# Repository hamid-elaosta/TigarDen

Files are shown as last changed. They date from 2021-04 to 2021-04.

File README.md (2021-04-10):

# TigarDen

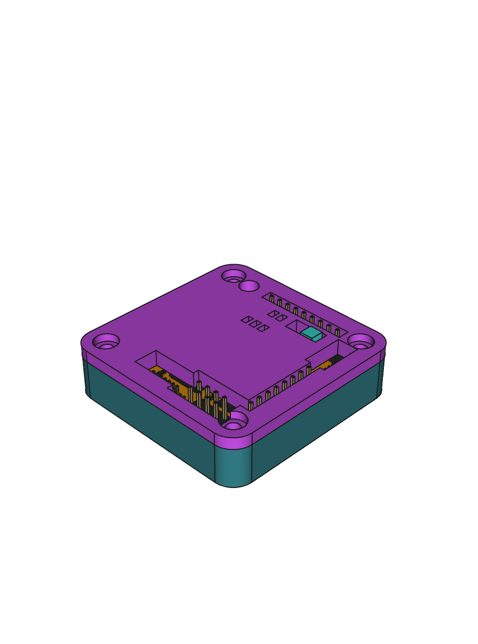
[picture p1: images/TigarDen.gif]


A 3D printable enclosure for the Tigard Open Source Hardware Hacking Tool from [Securing Hardware](https://securinghardware.com/)

# Enclosure

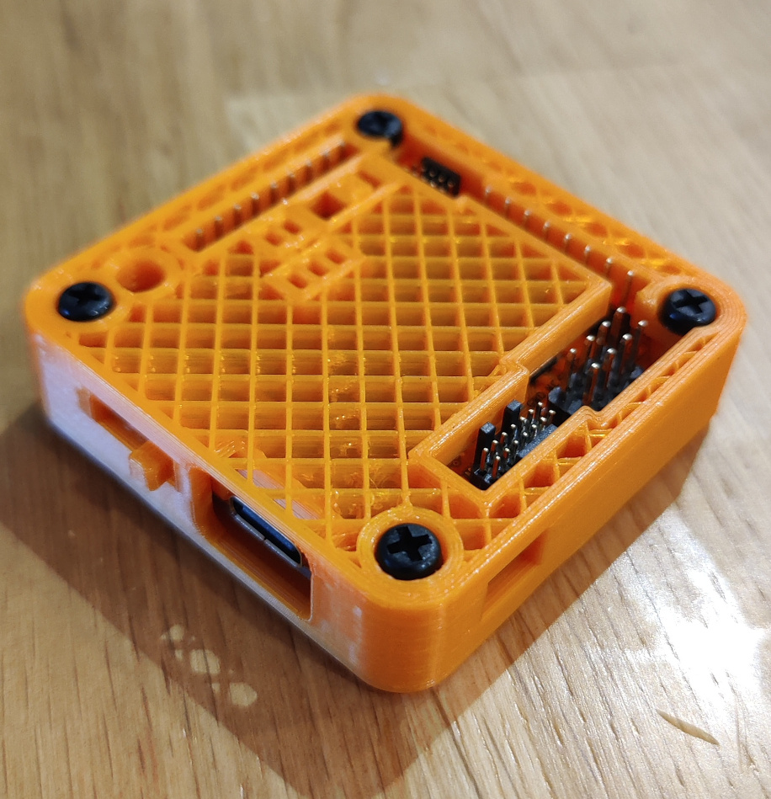
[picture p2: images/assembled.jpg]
 

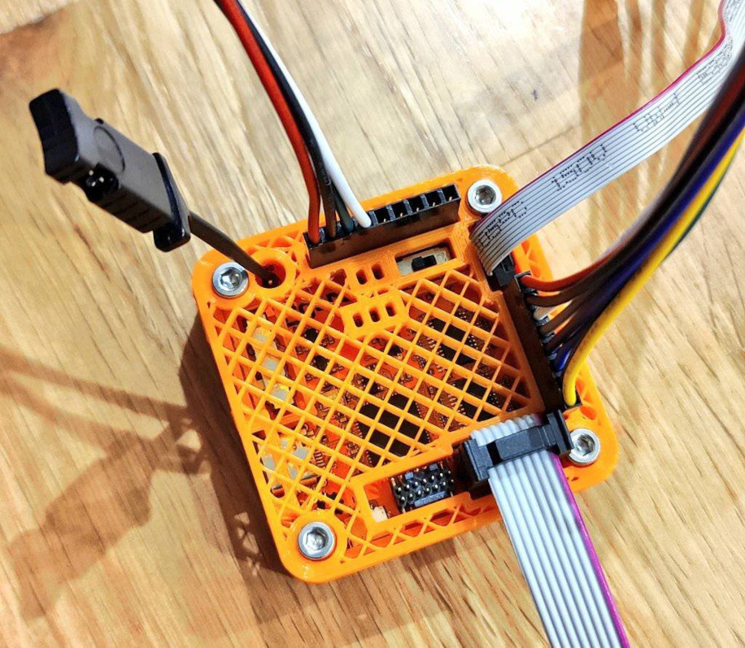
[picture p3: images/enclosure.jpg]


# Assembly Requirements

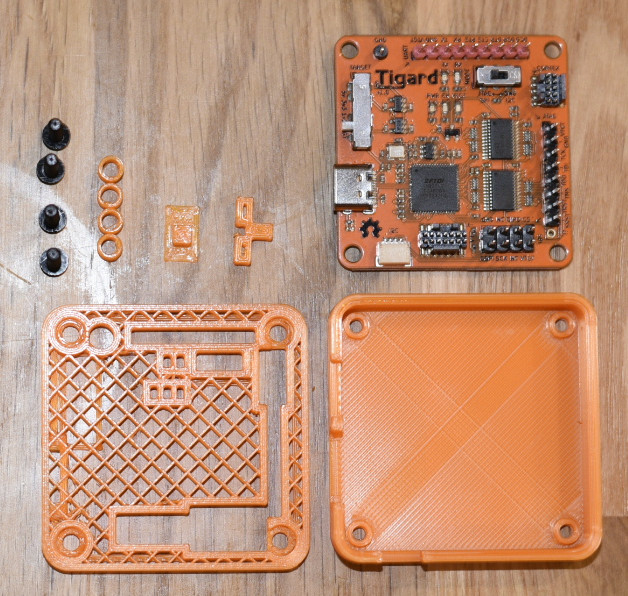
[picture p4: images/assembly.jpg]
 

* The enclosure comes in the following parts;
    * [top (STL)](Lid.stl)
    * [bottom (STL)](Base.stl)
    * [shim (STL)](Shim4mm.stl)
    * [voltage switch (STL)](VoltageSwitchNotched.stl)
    * [JTAG/SWD switch (STL)](JTAGSwitch.stl)

AND

* 4x M3x10; The base screw holes are sized for M3 tapping/self tapping (gently)
* 4x non-slip rubber feet for that extra flair (Optional)

OR
* 4x M3x14 Bolts
* 4x M3 Nyloc nuts as feet

# Printing

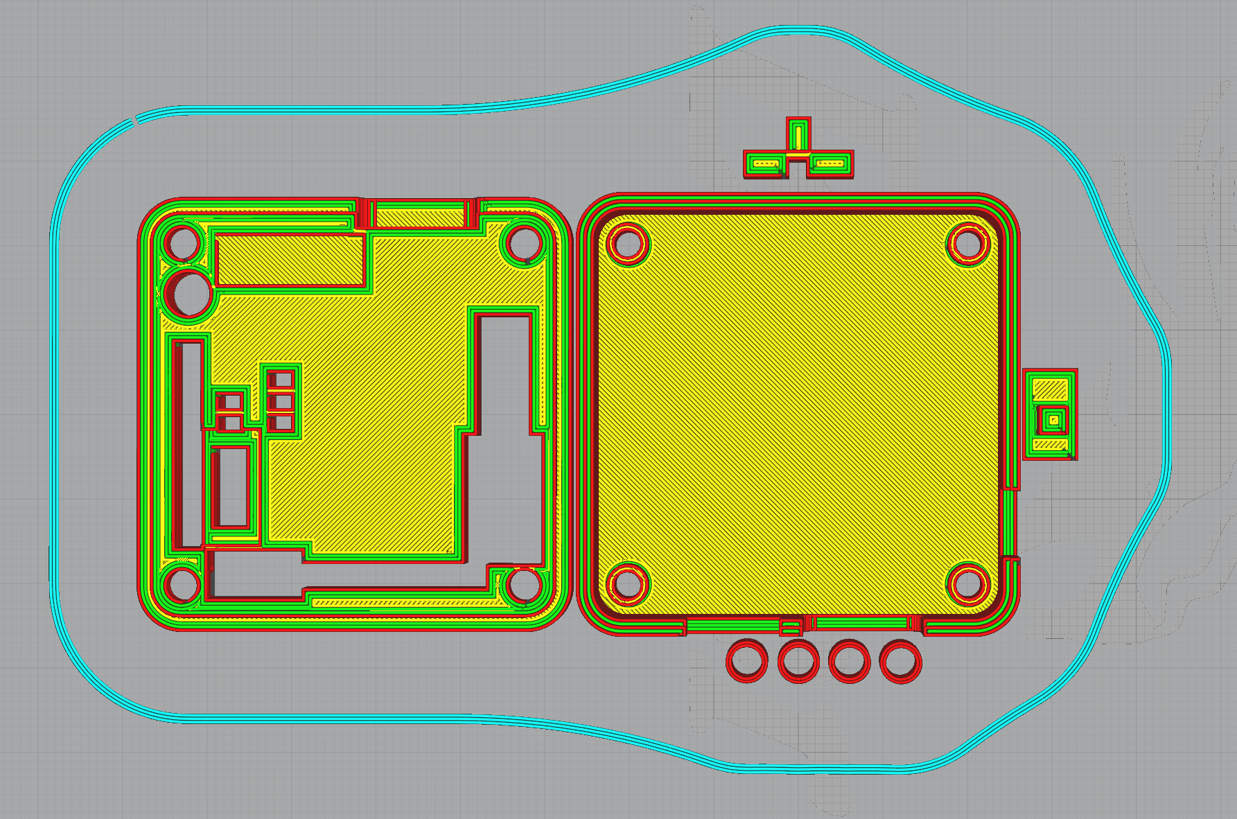
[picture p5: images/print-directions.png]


> Note: I don't recommend printing them all at once, you won't be able to select the top/bottomless grid for the lid this way anyway, this image is to indicate which way up to print. Voltage switch is printed notch-up.

For my print I sliced in Cura and printed at 0.2mm (Standard quality) (on an almost-stock Ender 3 V2), the tolerences in the design should be enough to allow for some variation in print quality.

Print the JTAG switch and base right-way-up, print the voltage switch (note it has a notch) and lid upside down; see below if you want to replicate the grid pattern.

> Note: The dimensions take into account the dimensions when printing without top and bottom layers for the lid, the lid may need adjustments if you choose to print with top and bottom layers on.

For the switches, I recommend printing multiples, spaced out on the print bed, this gives each layer time to cool before the next layer. I've found when printing tiny items like these, that the hotend will melt everything together if it stays over a small print too long, so i came up with this solution.

It means you have a few extras (if they print successfully) but a much higher chance of success in my experience.

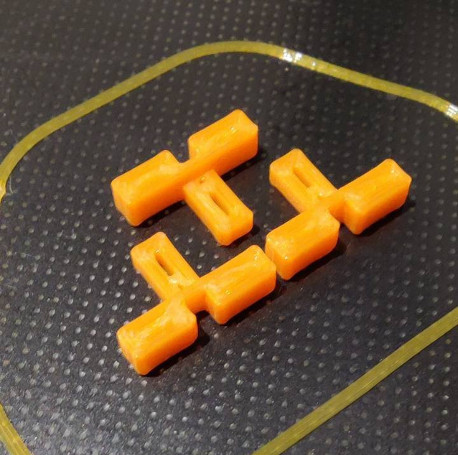
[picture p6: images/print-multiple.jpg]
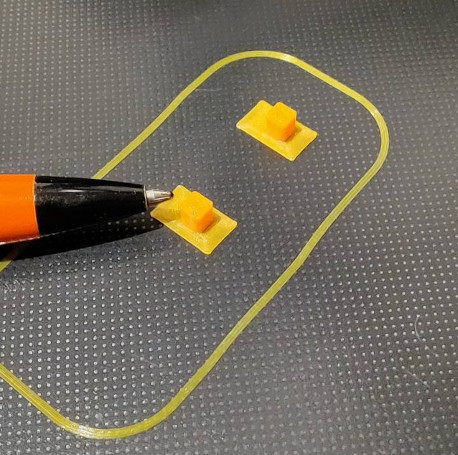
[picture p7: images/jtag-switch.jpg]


# Shims

The shims sit between the Tigard and the lid to hold it firmly in place so there is no play when connecting/disconnecting things to and from the board. The STL is exported at 4mm, these fit perfectly and the lid closes exactly with my print, but you may wish to export them again or modify the Z height in your slicer to adapt them.

# The Grid

If you wish to achieve the grid pattern shown in the photograph, disable top and bottom layers in your slicer, set infill type to "grid" and set your infill density according to the grid size you would like, the photo above is 25% infill.

# Modifying

The FreeCAD design file is [here](TigarDen.FCStd), modify to your hearts desire. I'm a FreeCAD/CAD beginner so I would appreciate any critique of the approach, raise a ticket or ping me on Twitter.

# Open Source Tools/Software

3D CAD model created with [FreeCAD 0.19 AppImage](https://freecadweb.org/) on [Manjaro Linux](https://manjaro.org/), images edited with [GIMP](https://www.gimp.org/), PNGs optimised with [pngcrush](https://pmt.sourceforge.io/pngcrush/), this document written in [VSCodium](https://vscodium.com/), prints sliced using [Ultimaker Cura](https://github.com/Ultimaker/Cura) and printed using [Marlin 2.0.x (3D Printer) Firmware](https://github.com/MarlinFirmware/Marlin).

# Links
* [Tigard Sources and Documentation](https://github.com/tigard-tools/tigard)
* [Tigard at Crowd Supply](https://www.crowdsupply.com/securinghw/tigard)

# License

Tigard is Copyright 2020 Franklin Harding CC BY-SA 4.0.

TigarDen © 2021 by Hamid Elaosta is licensed under CC BY-SA 4.0. To view a copy of this license, visit http://creativecommons.org/licenses/by-sa/4.0/

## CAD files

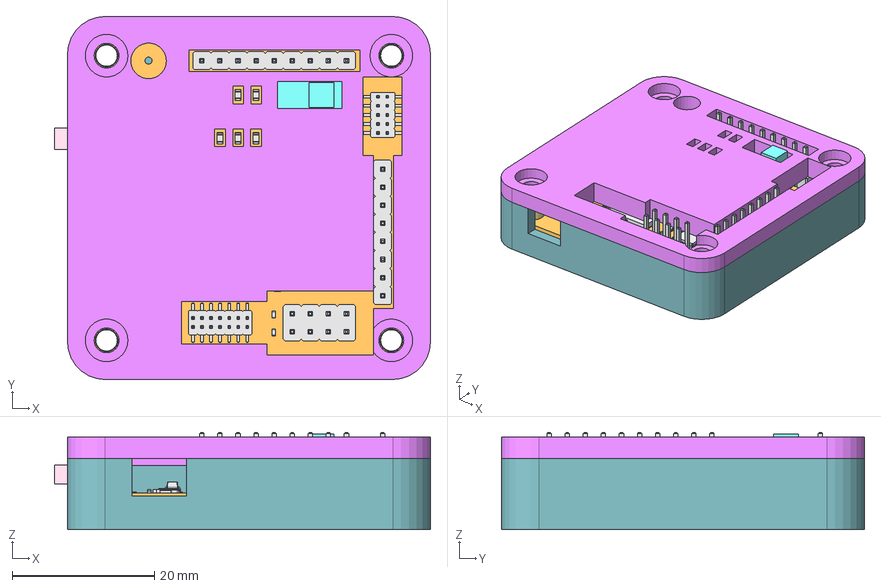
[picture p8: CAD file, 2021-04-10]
TigarDen.FCStd
52.8 x 51.0 x 13.6 mm
Pcb_1420
J6_PinHeader_2x07_P127mm_Vertical_SMD_5EEC7791
J1_Fusion_5EEC9037[2]
J2_PinHeader_1x08_P254mm_Vertical_5F30E631
U6_TSSOP_24_44x78mm_P065mm_5EEC89EE x 2
SW2_CuK_JS202011CQN_DPDT_straight_5EEC8CD7
J4_PinHeader_2x04_P254mm_Vertical_5EEC90DB
J5_PinHeader_2x05_P127mm_Vertical_SMD_5EEC7B2C
J3_PinHeader_1x09_P254mm_Vertical_5EEC791D
SW1_Part 1_5EEC7A8E
RN2_R_Array_Convex_4x0402_5EEC7FF7 x 8
C16_C_0402_1005Metric_5EEC7FC5 x 26
D1_LED_0603_1608Metric_5EEC8164 x 5
FB1_L_0402_1005Metric_5EEC96E1 x 3
R1_R_0402_1005Metric_5EEC9093 x 23
U3_QFN_64_1EP_9x9mm_P05mm_EP6x6mm_5EEC99E5
Q1_SOT_23_5EEC92A9
U1_SOT_23_5_5EEC8E77 x 2
U4_SOT_23_6_5EEC8D91
Y1_Crystal_SMD_3225-4Pin_3.2x2.5mm_5EEC7F91
Body Pocketed
Lid Pocketed
Voltage Switch
JTAG Switch
Shim1
Shim2
Shim3
Shim4

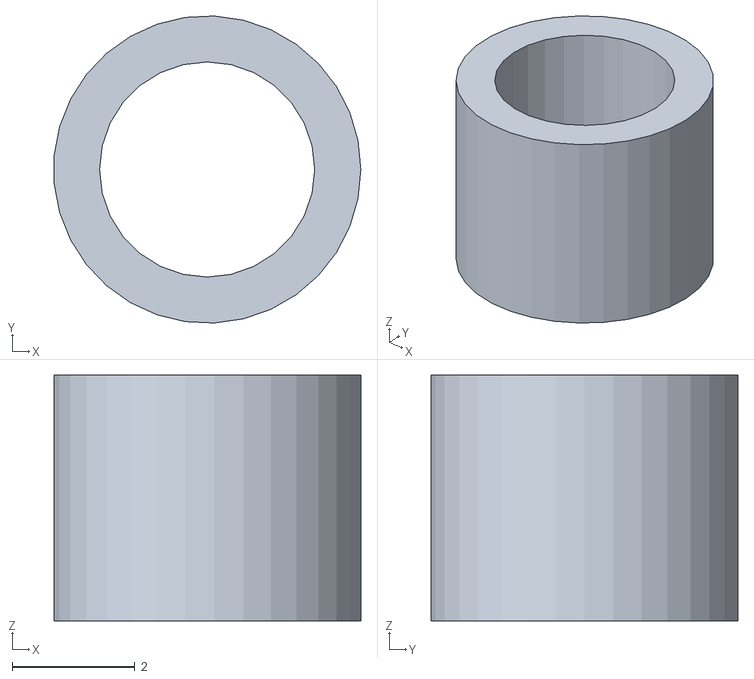
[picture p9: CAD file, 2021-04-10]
Shim4mm.stl
4.99 x 4.99 x 4.00

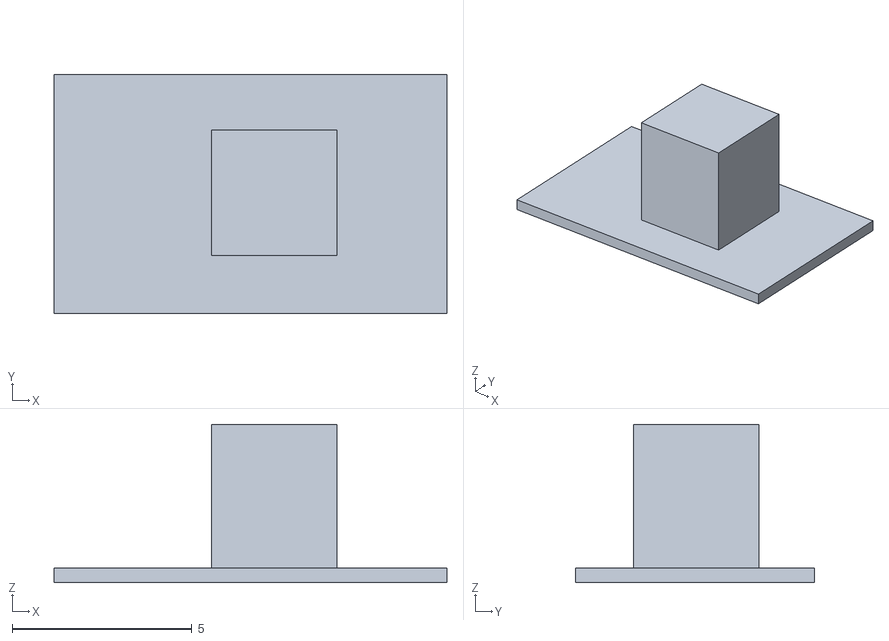
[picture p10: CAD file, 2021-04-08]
JTAGSwitch.stl
10.9 x 6.64 x 4.40

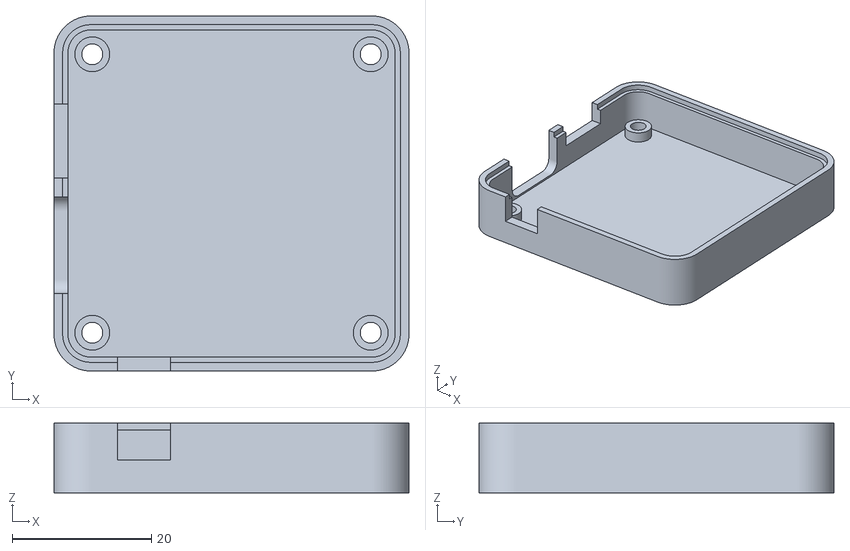
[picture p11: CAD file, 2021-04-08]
Base.stl
51.0 x 51.0 x 10.0

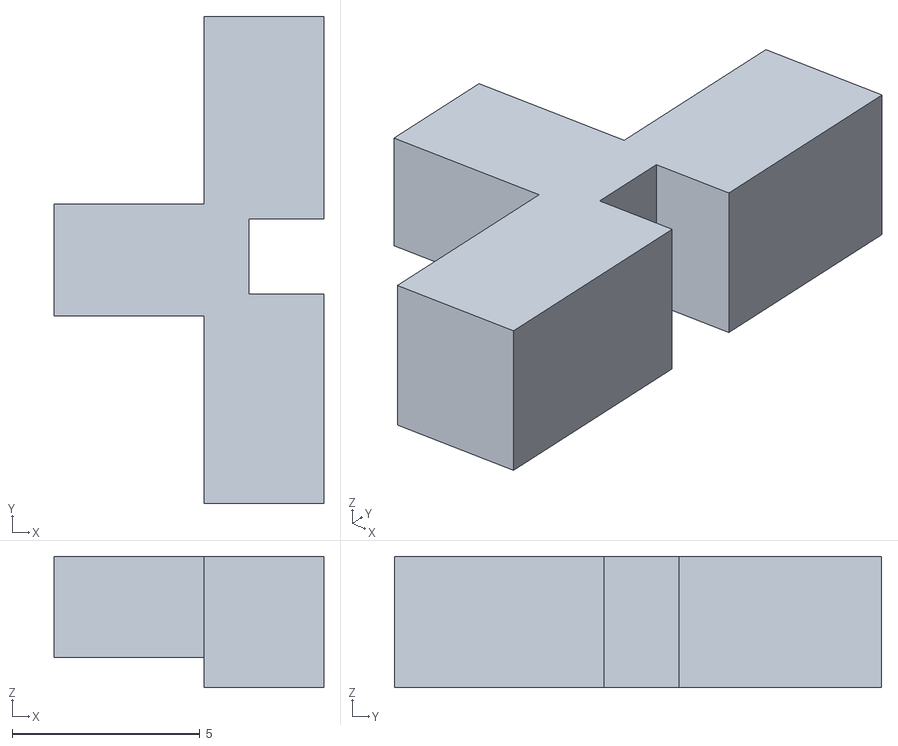
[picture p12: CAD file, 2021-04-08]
VoltageSwitchNotched.stl
7.20 x 13.0 x 3.50

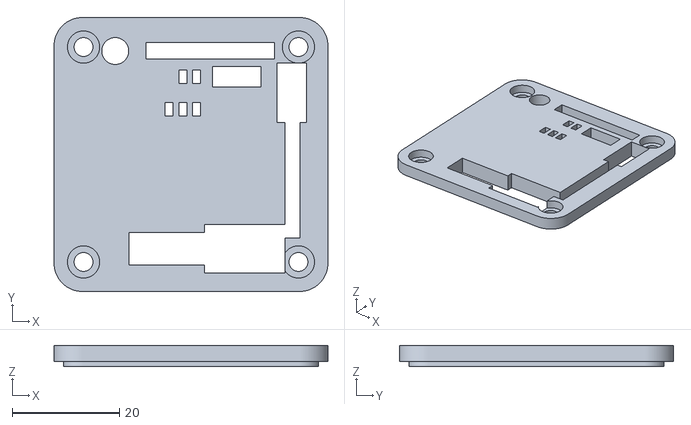
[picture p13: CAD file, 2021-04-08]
Lid.stl
51.0 x 51.0 x 4.00

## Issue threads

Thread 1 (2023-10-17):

DFM feedback

jwise, 2023-10-17:
Hi Hamid,

Great work on this case!

I have a little bit of design-for-manufacturability feedback that I'll put in an Issue, since you so requested :-)

My primary suggestion is that there is not a good orientation for the lid to be printed.  Specifically, if it is printed with the bottom side against the build plate, then the lip forms an overhang, and if it is printed with the top side against the build plate, then the recessed screw bosses form an overhang -- both of which are difficult to print.

I think my plan is to build a new top case that is a little more 'skeletal' that preserves the silkscreen legends, and includes the shims.  Where did you get the model of the Tigard itself?  Also, is it possible to export STEP files for these, rather than STLs?  If so, I'll just load the STEP file into Onshape and remix it that way, rather than modeling it from scratch.

Thanks!
joshua

jwise, 2023-10-19:
Here's my remix: https://www.printables.com/model/619978-tigarden-tigard-case-with-visible-pin-legends

hamid-elaosta, 2023-10-19:
Hey Joshua. Remix looks great.

Sorry about the delay in getting back to you; I imagine it should be possible to get STEP files, I guess I'm a little late for your needs though!

The model of the Tigard I got by importing the board design files from the Tigard repo

I'm a little surprised you'd have any issues printing this top-down on an X1C; it should be more than capable of printing the tiny overhang, but no reason not to improve it.

I printed the original orange one in PLA but I have some clear nylon which I think might be cool for the top of the case, I will have to give that a go.

I haven't tweaked the design in a while but I might make some updates if there's still interest in the case.

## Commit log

2021-04-08 Initial release
    [Base.stl, JTAGSwitch.stl, Lid.stl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]
2021-04-08 Add FreeCAD design file. Now it's truly open source! Update documentation
    [TigarDen.FCStd]
2021-04-10 Add shims to hold the Tigard nice and tight. Switch to nylon bolts without nuts Assembly gif Update images
    [Shim4mm.stl, TigarDen.FCStd]
